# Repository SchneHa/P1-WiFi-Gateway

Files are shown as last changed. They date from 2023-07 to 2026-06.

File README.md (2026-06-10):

### P1-WiFi-Gateway
P1-WiFi-Gateway mit Unterstützung der cFos Power Brain Wallbox

P1 wifi gateway 2022

**(English Version below)**

Basierend auf einem Repo von Ronald Leenes: https://github.com/romix123/P1-wifi-gateway

Diese Software vereint verschiedene Komponenten in einem handlichen Paket.
Die Software läuft auf einem ESP8266 board wie dem Wemos D1 mini oder mini Pro und hat einen bescheidenen Platzbedarf.

Die Datenverarbeitung basiert auf: http://domoticx.com/p1-poort-smart-meter-data-to-domoticz-esp8266 
Das Captive Portal basiert auf einem der ESP8266-Beispiele, die OTA-Einheit ebenfalls.

Das Modul liefert Daten über JSON- oder MQTT-Nachrichten an einen Host, kann aber auch über das Webinterface des Moduls oder per Telnet ausgelesen werden. Die Daten können an einen virtuellen Zähler "HTTP input" in der Power Brain Wallbox von cFos übertragen werden und dort für das Lastmanagement genutzt werden. Damit das funktioniert, muss der Charging Manager der Wallbox mindestens auf die Firmwareversion 1.17.4-beta gebracht werden.

Das Modul lädt beim Start zuerst den Pufferkondensator auf. Es blinkt dann 2x und versucht zunächst, sich mit Ihrem WLAN-Netzwerk zu verbinden. Während dieses Vorgangs blinkt die LED mit einer Periode von 0,5 Hz. Kommt keine Verbindung zustande, startet das Modul einen Access Point mit dem Namen P1_Setup. Verbinden Sie sich mit diesem Netzwerk und surfen Sie zu 192.168.4.1

Daraufhin erscheint der Menübildschirm des Moduls. Geben Sie dort die SSID und das Passwort Ihres WLAN-Netzwerks ein. Darunter tragen Sie die Daten des empfangenden Servers (IP und Portnummer) ein. Dies kann Ihr Domotociz-Server sein, in diesem Fall müssen Sie auch die IDx eingeben, die Domoticz für ein Gas- und ein Energiegerät erstellt. 
Auch die Daten für einen (z. B. auf einem Raspberry Pi selbst gehosteten) MQTT-Broker können jetzt eingegeben werden.

Wenn die Daten für das Lastmanagement einer cFos Power Brain Wallbox genutzt werden sollen, ist dies ebenfalls hier möglich.

In der jetzt veröffentlichten Version 1.2f ist es nun auch möglich, Gas-Verbrauchswerte über MQTT zu empfangen, die von einem Gassensor wie in meinem Repo https://github.com/SchneHa/Gas_Meter beschrieben gesendet werden. Es werden im Webinterface des P1-Gateways der Gas-Gesamtzähler und der aktuelle Tageszähler dargestellt. Dafür kann derselbe Broker wie für die anderen Werte angegeben werden, es kann aber auch ein anderer Broker sein.

Schließlich geben Sie an, wie viele Sekunden Daten an den Server gesendet werden sollen. DSMR4-Messgeräte verwenden ein Messintervall von 10 Sekunden. SMR5-Zähler liefern jede Sekunde Daten. Das erscheint  viel und das Modul benötigt auch viel Strom, daher ist die Frage, ob es parasitär (powered by the meter) arbeiten kann. Empfohlen ist  ein Intervall von 15 Sekunden oder höher. Das hier eingegebene Intervall wird nicht immer synchron zum Datenintervall des Zählers sein, gehen Sie also nicht davon aus, dass Sie in Domoticz, MQTT oder im Charging Manager der cFos Wallbox  genau alle x Sekunden einen Messwert sehen. 

Das Modul „schläft“ zwischen den Messungen (das Modem wird ausgeschaltet, so dass die Stromaufnahme von ca. 70 mA auf 15 mA sinkt). Dies gibt dem Pufferkondensator Zeit, sich für die vom WLAN-Sender des Moduls erzeugten Stromspitzen aufzuladen (und es spart dennoch etwas Strom (der von Ihrem Energieversorger bezahlt wird, aber trotzdem)). Jedes bisschen hilft.

Siehe http://esp8266thingies.nl für weitere Informationen über das Modul und http://www.esp8266thingies.nl/wp/forum-2/ für das Diskussionsforum.

Ergänzung vom 31.07.2023: Seit heute sind die PCB Dateien im KiCAD Format online. Das Board wurde schon produziert und getestet. Ebenso stehen die Gerber Dateien zur Verfügung.

grafik







Ich habe noch einige PCBs aus der ersten Produktion übrig, bei Bedarf bitte melden.
```
PCB unbestückt: 5€
PCB mit Bauteilen: 10€
PCB fertig bestückt: 15€
D1 mini ESP8266 mit Headern: 10€
inklusive Versand innerhalb Deutschlands
hans(dot)schneider(at)gmx(dot)ch
```

```
Version: 1.2f Datum: 29. Mai 2026
         Gasverbrauch (Gesamtzähler und Tageszähler), Import der Werte über MQTT implementiert
         Voraussetzung: Vorhandensein eines Gas-Sensors wie unter meinem Repo
         https://github.com/SchneHa/Gas_Meter beschrieben
Version: 1.2e Datum: 02.11.2025
         Checkt nun in jedem loop, ob eine Verbindung zum WiFi besteht. Wenn nicht, wird die
         Verbindung neu hergestellt.
Version: 1.2d Datum: 15.01.2025
         nach Ändern des voreingestellten Passworts für die cFos Power Brain wird das Passwort
         nun nicht mehr vergessen
Version: 1.2c Datum: 23.05.2024
         die Anzeige der Seite mit den Messwerten wird nun alle 20 Sekunden erneuert
         P1meter sendet nun positive Werte für actualElectricityPowerDelivered und negative Werte
         für actualElectricityPowerReturned zur cFos Power Brain Wallbox (das ist wichtig um
         korrekte Werte für die Einspeisung ins Stomnetz zu erhalten)
Version: 1.2b Datum: 22.05.2023
         Anpassungen für die Firmware 1.19.4 der cFos Power Brain Wallbox
         (power_va ist nun power_w, is_va existiert nicht mehr)
         Korrekturen der niederländischen, französischen und schwedischen Version
Version: 1.2a Datum: 13.03.2023
         Fertigstellung der französischen und schwedischen Version
         diverse Verbesserungen und Fehlerbehebungen
Version: 1.2 Datum: 05.03.2023, Autor: Hans Schneider
         Unterstützung für den HTTP_input Zähler der cFos Power Brain Wallbox hinzugefügt
         diverse Verbesserungen und Fehlerbehebungen
Version: 1.1adc Datum: 12.02.2023 Autor: Ronald Leenes
1.1adc: Umfangreiche Protokollierung implementiert
        Schwedische Version aktualisiert, um sie an die niederländische Version anzugleichen 
        (Deutsche und Französische Version haben keine Sicherheitsfunktionen bei Setup/Update)
1.1aa: Fehlerkorrekturen 1.1: Graphen implementiert BerichtstarifIndicatorElectricity behoben
ud: Kopfzeilen aktualisieren behoben ua: Problem mit Setup-Feldern behoben
u: Passwortschutz für Setup- und Update-Firmware-Menüs hinzugefügt
   Gehen Sie beim ersten Booten von Version 1.0u innerhalb von 60 Sekunden zum Setup-Menü, um den
   Passwortschutz zu umgehen
   Out-of-the-Box-Unterstützung für die Integration von Home Assistant "DSMR Reader" hinzugefügt 
   Verwenden Sie „dsmr“ als MQTT-Präfix und Daten werden automatisch im „DSMR Reader“-Format an den
   MQTT-Broker geliefert
   MQTT-Wiederverbindung behoben, es ist jetzt nicht blockierend
   Zurücksetzen der Hardboot-Tageszähler behoben
   Senden leerer MQTT-Nachrichten behoben
   Insgesamt verbesserte Stabilität
t: Verbesserungen bei der Energieverwaltung
   allgemeine (kleinere) Bereinigung
ta: Korrektur für Telnet-Berichte
    französische Lokalisierung hinzugefügt
s: deutsche Lokalisierung hinzugefügt 
   mqtt-Ausgabe für schwedische spezifische OBIS-Codes hinzugefügt
r: Geschwindigkeitsverbesserungen und Rationalisierung der Parser-Lokalisierungen für: NL, SE
q: Tageswerte hinzugefügt 
p: EquipmentID in mqtt set eingebaut 
o: fixe Gasleistung, fixes mqtt reconnect 
n: leerer Aufruf von SetupSave leitet jetzt zum Hauptmenü weiter statt Einstellungen zurückzusetzen ;-)
   behobene kWh/Wh Invertierung 
m: setupsave fix, relocate to p1wifi.local nach 60 Sek. mqtt 
   kw/W fix 
l: wifireconnect nach WLAN-Verlust 
k: großer BUG behoben, SoftAP würde keinen erreichbaren Webserver erzeugen 
j: Rohdaten auf Port 23
   Hauptcodeumschreibung 
   implementierte Datenberichtsmethoden: geparste Daten: json, mqtt, p1wifi.local/P1 
   Rohdaten: Telnet auf Port 23, p1wifi.local/Data
i: erweiterte maximale Leitungslänge für TD210-D-Zähler, die eine wirklich lange 1-0:99.97.0-Leitung haben 
h: erweitertes mqtt-Set mit sofortigen Leistungen, Spannungen, aktueller Tarifgruppe 
   Stromausfälle, Stromabfälle 
g: feste mqtt
```

Empfohlenes Board:

Wemos D1 mini Pro, Flash Größe: 16 MB, FS: 14 MB, OTA: ~1019 kB

ebenso möglich:

Wemos D1 R2 & mini, Flash Größe: 4 MB, FS: 2 MB, OTA: ~1019 kB oder jedes andere kompatible board

```
Benötigte Dateien:
  P1WG2022current.ino
  CRC16.h 
  JSON.ino 
  MQTT.ino 
  TELNET.ino 
  debug.ino 
  decoder.ino 
  functions.ino 
  graph.ino
  logging.ino
  vars.h
  webserver.ino
  webserverDE.ino
  webserverFR.ino
  webserverNL.ino
  webserverSE.ino
  wifi.ino
```
Anmerkung: <Del>Zurzeit sind nur die deutsche und die niederländische Versionen lauffähig.</Del> Bei der französischen und der schwedischen Version muss ggf. die Übersetzung korrigiert werden.

**English Version:**

P1-WiFi-Gateway with support for cFos Power Brain Wallbox

P1 wifi gateway 2022

Based on a repo of Ronald Leenes: https://github.com/romix123/P1-wifi-gateway

This software combines various components in one handy package.
The software runs on an ESP8266 board like the Wemos D1 mini or mini Pro and has a modest footprint.

The data processing is based on: http://domoticx.com/p1-poort-smart-meter-data-to-domoticz-esp8266
The captive portal is based on one of the ESP8266 samples, as is the OTA unit.

The module delivers data to a host via JSON or MQTT messages, but can also be read out via the module's web interface or via Telnet. It is possible to send data to a virtual meter "HTTP input" of the Power Brain Wallbox of cFos which can be used to implement load management. For that to work Charging Manager of cFos Power Brain Wallbox has to be at least on firmware version 1.17.4-beta.

When starting, the module first charges the buffer capacitor. It will then blink 2x and first try to connect to your WiFi network. During this process, the LED flashes with a period of 0.5 Hz. If no connection is established, the module starts an access point with the name P1_Setup. Connect to this network and surf to 192.168.4.1

The module menu screen appears. Enter the SSID and password of your WiFi network there. Below this, enter the data of the receiving server (IP and port number). This can be your Domotociz server, in this case you also have to enter the IDx that Domoticz creates for a gas and an energy device.
The data for an MQTT broker (e.g. hosted on a Raspberry Pi itself) can now also be entered.

If the data is to be used for load management of a cFos Power Brain Wallbox, this is also possible here.

In the newly released version 1.2f, it is now also possible to receive gas consumption data via MQTT, sent by a gas sensor as described in my repository https://github.com/SchneHa/Gas_Meter. The total gas meter reading and the current daily meter reading are displayed in the P1 gateway's web interface. The same broker used for the other values can be specified for this, or a different broker can be used.

Finally, specify how many seconds of data should be sent to the server. DSMR4 gauges use a measurement interval of 10 seconds. SMR5 counters provide data every second. That seems a lot to me and the module also draws a lot of current, so the question is whether it can operate parasitically (powered by the meter). I recommend an interval of 15 seconds or higher. The interval entered here will not always be in sync with the meter's data interval, so don't assume that you will see a reading in Domoticz, MQTT or in Charging Manager of the cFos Wallbox exactly every x seconds. 

The module "sleeps" between the measurements (the modem is switched off so that the current consumption drops from approx. 70 mA to 15 mA). This gives the buffer capacitor time to charge up for the current spikes generated by the module's WiFi transmitter (and it still saves some electricity (which is paid for by your utility, but still)). Every little helps.

See http://esp8266thingies.nl for more information about the module and http://www.esp8266thingies.nl/wp/forum-2/ for the discussion forum.

Addition from 07/31/2023: Since today the PCB files in KiCAD format are online. The board has already been produced and tested. The Gerber files are also available.

grafik







I still have some PCBs left from the first batch, please let me know if you need one.

```
PCB unassembled: 5€
PCB with parts: 10€
PCB assembled: 15€
D1 mini ESP8266 with headers: 10€
shipping to Germany included
hans(dot)schneider(at)gmx(dot)ch
```

```
Version: 1.2f Date: 29.5.2026
         Gas consumption (Total counter and daily counter), import of the values via MQTT implemented
         Requirement: A Gas sensor as described in my repo https://github.com/SchneHa/Gas_Meter must
         be available
Version: 1.2e Date: 02.11.2025
         now checks connection to wifi in every loop, if not connected it will be reconnected
Version: 1.2d Date: 15.01.2025
         after changing cFos Power Brain password from it's default the new password isn't forgotten anymore now
Version: 1.2c Date: 23.05.2024
         measurement page refreshes every 20 seconds now
         P1meter now sends positive values for actualElectricityPowerDelivered and negative values for
         actualElectricityPowerReturned to cFos Power Brain wallbox (that is important to calculate correct
         values for feeding energy into the power grid)
Version: 1.2b Date: 22.05.2023
         changes for cFos Power Brain Firmware 1.19.4
         (power_va is now power_w, is_va doesn't exist anymore)
         improvements of dutch, french and swedish language
Version: 1.2a Date: 13.03.2023
         Finishing the french and swedish Version
         various Improvements and bug fixes
Version: 1.2 Date: 03/05/2023, Author: Hans Schneider
         added Support for the HTTP_input meter of cFos Power Brain Wallbox
         various improvements and bug fixes
Version: 1.1adc Date: 02/12/2023 Author: Ronald Leenes
1.1adc: Extensive logging implemented
        Swedish version updated to match Dutch version 
        (German and French versions have no security features on setup/update)
1.1aa: Bug fixes 1.1: Graphs implemented
       Reporting TariffIndicatorElectricity fixed
ud: fixed update headers 
ao: fixed problem with setup fields
u: Added password protection for setup and update firmware menus when booting version 
1.0u for the first time, go to setup menu within 60 seconds to bypass password protection
     Added out-of-the-box support for Home Assistant "DSMR Reader" integration 
     Use "dsmr" as MQTT prefix and data is automatically delivered to the MQTT broker in "DSMR Reader" format
     Fixed MQTT reconnection, it's non-blocking now
     Fixed resetting hardboot day counters
     Fixed sending empty MQTT messages
     Improved overall stability
t: Power management improvements
   general (minor) cleanup 
ta: Fix for telnet reports
    added French localization
s: added german localization
   added mqtt output for swedish specific OBIS codes
r: Speed improvements and streamlining of parser 
   localizations for: NL, SE
q: daily values added 
p: EquipmentID built into mqtt set 
o: fixed gas power
   fixed mqtt reconnect 
n: empty call to SetupSave now redirects to main menu instead of resetting settings ;-)
   fixed kWh/Wh inversion 
m: setupsave fix, relocate to p1wifi.local after 60 sec. 
   mqtt - kw/W fix 
l: wifi reconnect after WLAN loss 
k: major BUG fixed
   SoftAP would not create an accessible web server 
j: raw data on port 23 
   main code rewrite
   implemented data reporting methods: parsed data: json, mqtt, p1wifi.local/P1 
   raw data: telnet on port 23, p1wifi.local/Data
i: extended maximum line length for TD210-D meters that have a really long 1-0:99.97.0 line 
h: extended mqtt set with instantaneous powers, voltages, current tariff group
   blackouts, blackouts 
g: fixed mqtt
```

Recommended board:

Wemos D1 mini Pro, Flash Größe: 16 MB, FS: 14 MB, OTA: ~1019 kB

also possible:

Wemos D1 R2 & mini, Flash Größe: 4 MB, FS: 2 MB, OTA: ~1019 kB or any other compatible board

Files needed:
```
  P1WG2022current.ino
  CRC16.h
  JSON.ino
  MQTT.ino
  TELNET.ino
  debug.ino
  decoder.ino
  functions.ino
  graph.ino
  logging.ino
  var.h
  webserver.ino
  webserverDE.ino
  webserverFR.ino
  webserverNL.ino
  webserverSE.ino
  wifi.ino
```

Note: <Del>Only the German and Dutch versions are currently working.</Del> The French and the Swedish version needs improvement of translation.

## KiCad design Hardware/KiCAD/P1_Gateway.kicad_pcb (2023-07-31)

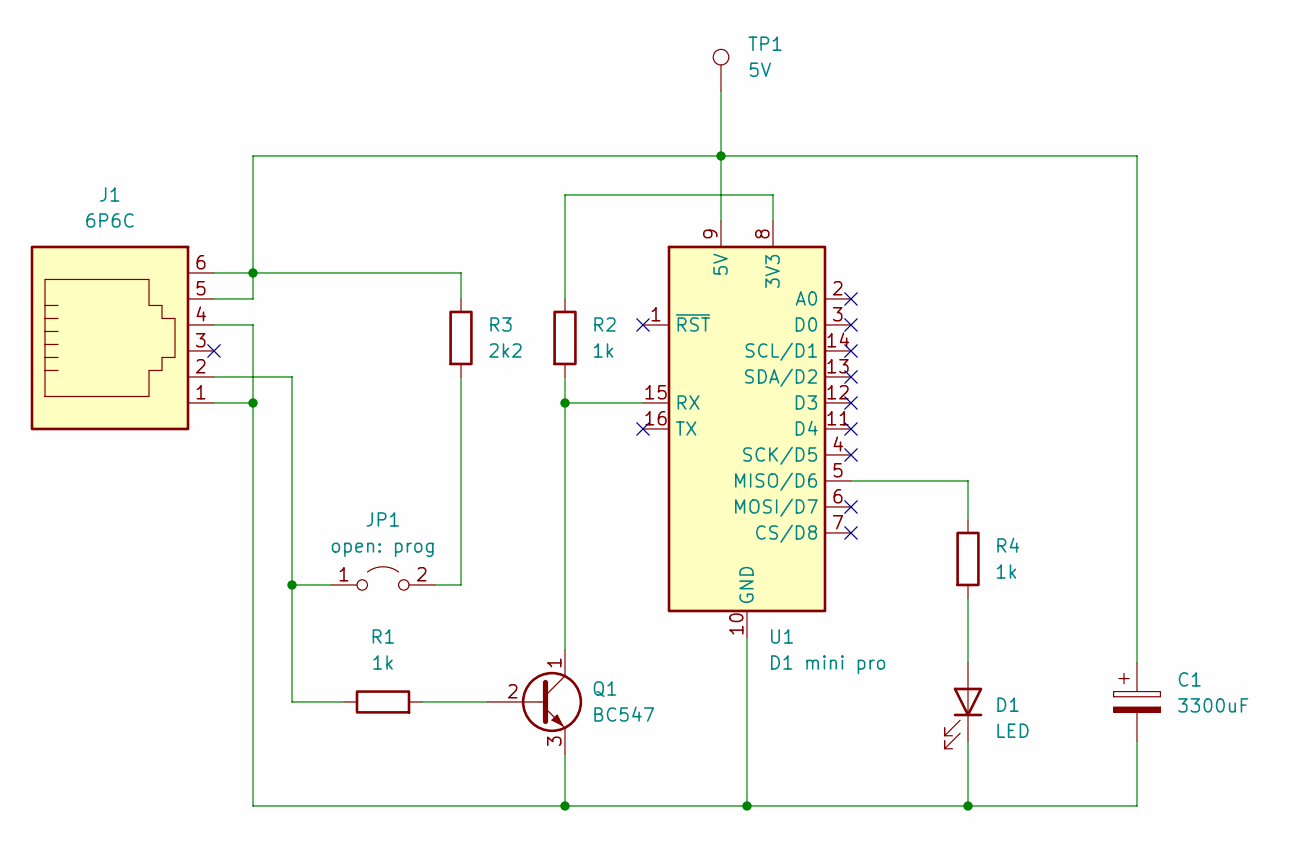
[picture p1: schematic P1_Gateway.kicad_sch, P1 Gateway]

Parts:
C1: 3300uF; CP_Radial_D5.0mm_P2.50mm
D1: LED; LED_D3.0mm
J1: 6P6C; RJ12_Amphenol_54601
JP1: open: prog; TestPoint_2Pads_Pitch2.54mm_Drill0.8mm
Q1: BC547; TO-92L_Inline_Wide
R1, R2, R4: 1k; R_Axial_DIN0204_L3.6mm_D1.6mm_P7.62mm_Horizontal
R3: 2k2; R_Axial_DIN0204_L3.6mm_D1.6mm_P7.62mm_Horizontal
TP1: 5V; TestPoint_Keystone_5000-5004_Miniature
U1: D1 mini pro; WEMOS_D1_mini_light

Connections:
unnamed: C1.1, J1.5, J1.6, R3.1, TP1.1, U1.9 (5V)
unnamed: C1.2, D1.1 (K), J1.1, J1.4, Q1.3 (E), U1.10 (GND)
unnamed: D1.2 (A), R4.2
unnamed: J1.2, JP1.1 (A), R1.1
unnamed: JP1.2 (B), R3.2
unnamed: Q1.1 (C), R2.2, U1.15 (RX)
unnamed: Q1.2 (B), R1.2
unnamed: R2.1, U1.8 (3V3)
unnamed: R4.1, U1.5 (MISO/D6)

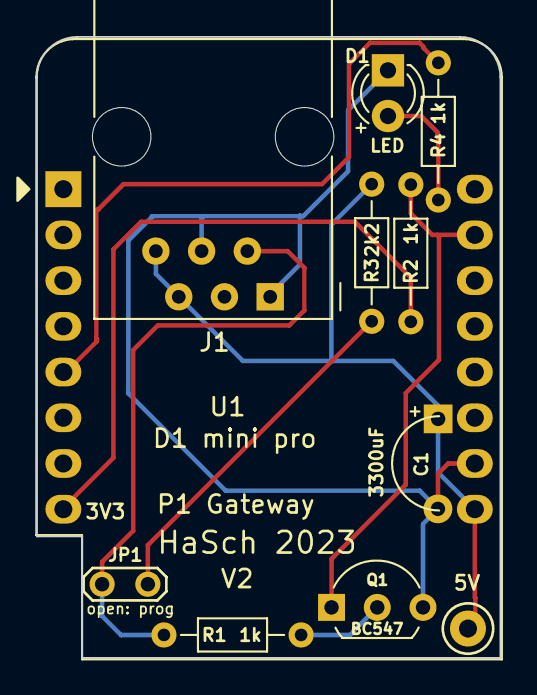
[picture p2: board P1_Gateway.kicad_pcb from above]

Board: 2 copper layers, 25.8 x 34.5 mm, 11 parts (0 on the bottom side), 9 nets.

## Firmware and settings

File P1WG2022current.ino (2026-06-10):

#include <ESP8266LLMNR.h>

 /*
 * Copyright (c) 2022 Ronald Leenes
 *
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
 */
/*
 * @file P1WG2022current.ino
 * @author Ronald Leenes
 *         Hans Schneider
 * @date 02.11.2025
 * @version 1.2f
 *
 * @brief This file contains the main file for the P1 wifi gatewway
 *
 * @see http://esp8266thingies.nl
 */
 
/*
 * P1 wifi gateway 2022
 * 
 * Deze software brengt verschillende componenten bij elkaar in een handzaam pakket.
 * 
 * De software draait op een ESP8285 of ESP8266 en heeft een bescheiden voetafdruk.
 * 
 * De data processing is gebaseerd op: http://domoticx.com/p1-poort-slimme-meter-data-naar-domoticz-esp8266/
 * De captive portal is gebaseerd op een van de ESP8266 voorbeelden, de OTA eenheid eveneens.
 * 
 * De module levert data aan een host via JSON of MQTT messages, maar kan ook via de webinterface van de module of via telnet worden uitgelezen
 * 
 * De module zal bij opstarten eerst de buffercondensator laden. 
 * Vervolgens knippert hij 2x en zal eerst proberen te koppelen aan je wifi netwerk. Gedurende dat proces zal de LED knipperen
 * met een periode van 0.5 Hz.
 * Wanneer geen verbinding kan worden gemaakt start de modiule een Access point onder de naam P1_Setup
 * Verbind met dit netwerk en surf naar 192.168.4.1
 * 
 * Het menuscherm van de module verschijnt dan. Vul daar SSID en wachtwoord van je wifi netwerk in. 
 * Daaronder vul je gegevens van de ontvangede server in (IP en poortnummer). Dit kan je DOmotociz server zijn
 * In dat geval moet je ook het IDx dat Domoticz maakt voor een Gas device en een Energy device invoeren.
 * Tenslotte geef je aan per hoeveel seconde je data naar de server wilt laten sturen.
 * DSMR4 meters hanteren een meetinterval van 10 sec. SMR5 meters leveren iedere seconde data. Dat lijkt me wat veel en 
 * kost de module ook veel stroom waardoor het maar de vraag is of hij parasitair (door de meter gevoed) kan werken.
 * Ik raad een interval van 15 sec of hoger aan. Het interval dat je hier invoert zal niet altijd synchroon lopen met
 * het data interval van de meter, ga er dus niet van uit dat je exact iedere x seconden een meetwaarde ziet in DOmoticz. 
 * Tussen metingen 'slaapt' de module (de modem wordt afgeschakeld waardoor het stroomverbruik van zo'n 70mA terugvalt naar 15 mA). 
 * Dit geeft de bufferelco tijd omm op te laden voor de stroompiekjes die de wifi zender van de module produceert 
 * (en het bespaart hoe dan ook wat stroom (die weliswaar door je energieleverancier wordt betaald, maar toch). Alle kleine 
 * beetjes helpen..
 *
 *  informatie, vragen, suggesties ed richten aan romix@macuser.nl 
 *  
 *  
 *    
 *  versie: 1.2f
 *  datum:  29 Januar 2026
 *  auteur: Ronald Leenes
 *          Hans Schneider
 *
 *  1.2f   implemented reading Gas values provided of an extern smart gas meter via MQTT
 *  1.2e   now checks connection to wifi in every loop, if not connected it will be reconnected
 *  1.2d   after changing cFos Power Brain password from it's default the new password isn't now forgotten anymore
 *  1.2c   measurement page refreshes every 20 seconds now
 *         P1meter now sends positive values for actualElectricityPowerDelivered and negative values for
 *         actualElectricityPowerReturned to cFos Power Brain wallbox. That is important to calculate correct
 *         values for feeding energy into the power grid.         
 *  1.2b   changes for cFos Power Brain FW 1.19.4: power_va is now power_w, is_va doesn't exist anymore
 *         improvements of Netherlands, French and Swedish language 
 *  1.2ab  display of module voltage in footer of webserver pages (re)activated, bug fixes
 *  1.2a:  debugging French and Swedish versions and improvements of translations (needs to be checked)        
 *  1.2:   bug fixes
 *         improvements for T211 SmartMeter in Belgium
 *         implemented support for HTTP input meter in cFos Power Brain wallbox  
 *           note: for this to work your cFos Charging Manager firmware has to be at least 1.17.4-beta
 *         debugging French and Swedish versions and improvemehandlents of translations (needs to be checked)
 *  1.1b   cleaning up, bug fixes, cosmetic changes
 *  1.1adc
 *  1.1ad: bug fixes and graph improvements
 *  1.1aa: bug fixes
 *  1.1: implemented graphs
 *  
 *  
 *  ud: fixed refreshheader
 *  ua: fixed setup field issue
 *  u: 
 *    password on Setup and Firmware Update
 *    made mqtt re-connect non-blocking
 *    incorporated "DSMR Reader" mqtt topics 
 *    fixed hardboot daycounters reset
 *    fixed sending empty MQTT messages
 *  
 *  t: improvements on powermanagement, overall (minor) cleanup
 *  ta: fix for Telnet reporting
 *  
 *  s: added German localisation
 *        Added mqtt output for Swedish specific OBIS codes
 *        
 *  r: speed improvements and streamlining of the parser
 *      localisations for: NL, SE
 *      
 *  q: added daily values
 *  p: incorporated equipmentID in mqtt set
 *  o: fixed gas output, fixed mqtt reconnect
 *  n: empty call to SetupSave now redirects to main menu instead of resetting settings ;-)
 *      fixed kWh/Wh inversion
 *  m: setupsave fix, relocate to p1wifi.local na 60 sec 
 *      mqtt - kw/W fix
 *  l: wifireconnect after wifi loss
 *  k: fixed big BUG, softAP would not produce accessible webserver.
 *  j: raw data on port 23
 *      major code rewrite
 *      implemented data reporting methods: 
 *        parsed data: json, mqtt, p1wifi.local/P1
 *        raw data: telnet on port 23, p1wifi.local/Data
 *        
 *  i:  extended max line length for TD210-D meters, which have a really loong 1-0:99.97.0 line
 *  h:  extended mqtt set with instant powers, voltages, actual tarif group. power outages, power drops
 *  g: fixed mqtt
 *  
 *  Generic ESP8285 module 
 *  Flash Size: 2mb (FS: 128Kb, OTA: –960Kb) 
 *   
 *  needed files: 
 *  this one (obv), 
 *  vars.h            in the process of moving all vars here
 *  lang.h
 *  CRC16.h
 *  JSON.ino
 *  MQTT.ino
 *  TELNET.ino
 *  debug.ino
 *  decoder.ino
 *  functions.ino
 *  graph.ino
 *  webserver.ino
 *  webserverDE.ino 
 *  webserverSE.ino
 *  webserverNL.ino
 *  wifi.ino
 *   
 */

bool zapfiles = false; //false; //true;

#define GERMAN // GERMAN / FRENCH / NEDERLANDS / SWEDISH

#ifdef GERMAN
  String sfx = "DE";
#endif
#ifdef FRENCH
  String sfx = "FR";
#endif
#ifdef NEDERLANDS
  String sfx = "NL";
#endif
#ifdef SWEDISH
  String sfx = "SE";
#endif

String version = "1.2f – " + sfx;

#define HOSTNAME "p1meter"
//#define HOSTNAME_G "Gas"
#define FSystem 1 // 0 = LittleFS 1 = SPIFFS

#define GRAPH 1
#define V3
#define DEBUG 1 //0 //1 //2 //3 // 1 is on serial only, 2 is serial + telnet
#define ESMR5 1
//#define SLEEP_ENABLED

#define LED_BUILTIN 2

const uint32_t  wakeTime = 90000; // stay awake wakeTime millisecs
const uint32_t  sleepTime = 5000; // sleep sleepTime millisecs

#if DEBUG == 1
  const char* host = "P1test";
  #define BLED LED_BUILTIN
  #define debug(x) Serial.print(x)
  #define debugf(x) Serial.printf(x)
  #define debugff(x,y) Serial.printf(x,y)
  #define debugfff(x,y,z) Serial.printf(x,y,z)
  #define debugln(x) Serial.println(x)
#elif DEBUG == 2
  #define BLED LED_BUILTIN
  #define debug(x) Serial.print(x);if(telnetConnected)telnet.print(x)
  #define debugf(x) Serial.printf(x)
  #define debugff(x,y) Serial.printf(x,y)
  #define debugfff(x,y,z) Serial.printf(x,y,z)
  #define debugln(x) Serial.println(x);if(telnetConnected)telnet.println(x)
#elif DEBUG == 3
  const char* host = "P1home";
  #define BLED LED_BUILTIN
  #define debug(x)
  #define debugln(x)
  #define debugf(x)
  #define debugff(x,y)
  #define debugfff(x,y,z)
#else
  const char* host = "P1wifi";
  #define BLED LED_BUILTIN
  #define debug(x)
  #define debugln(x)
  #define debugf(x)
  #define debugff(x,y)
  #define debugfff(x,y,z)
#endif

#define errorHalt(msg) {debugln(F(msg)); return;}

#define NUM(off, mult) ((P1timestamp[(off)] - '0') * (mult))   // macro for getting time out of timestamp, see decoder

#define ToggleLED  digitalWrite(BLED, !digitalRead(BLED));
#define LEDoff  digitalWrite(BLED, HIGH);
#define LEDon   digitalWrite(BLED, LOW);
#define OE  16 //IO16 OE on the 74AHCT1G125 
#define DR  4  //IO4 is Data Request
#define WLED 12  //IO12 (D6) is WiFi-LED, uncomment if it's present

#include <TZ.h>
#define MYTZ TZ_Europe_Amsterdam
#include <TimeLib.h>
#include <coredecls.h> // settimeofday_cb()
#include <MyAlarm.h>

#include <ESP8266WiFi.h>
#include <ESP8266HTTPClient.h>
#include <WiFiUdp.h>
#include "CRC16.h"

#if GRAPH == 1
  #if FSystem == 0
    #include <LittleFS.h>
    #define FST LittleFS
  #elif FSystem == 1
    #include "FS.h" //SPIFFS
    #define FST SPIFFS
  #endif
  File file;
#endif


// van ESP8266WiFi/examples/WiFiShutdown/WiFiShutdown.ino
#ifndef RTC_config_data_SLOT_WIFI_STATE
  #define RTC_config_data_SLOT_WIFI_STATE 33u
#endif
#include <include/WiFiState.h>  // WiFiState structure details
//#include <WiFiState.h>  // WiFiState structure details
WiFiState WiFistate;


//van captive portal
/*  ============================================================================================================

    Captive Portal based on:
    https://gitlab.com/MrDIYca/code-samples/-/raw/master/esp8266_setup_portal.ino

    For more info, please watch my video at https://youtu.be/1VW-z4ibMXI
    MrDIY.ca
  ============================================================================================================== */
#include <EEPROM.h>
#include <ESP8266WebServer.h>
ESP8266WebServer    server(80);

#include <WiFiClient.h>
#include <ESP8266mDNS.h>


// mqtt stuff . https://github.com/ict-one-nl/P1-Meter-ESP8266-MQTT/blob/master/P1Meter/P1Meter.ino
#include <PubSubClient.h>
WiFiClient espClient;                   // * Initiate WIFI client
PubSubClient mqtt_client(espClient);    // * Initiate MQTT client
bool MQTT_Server_Fail = false;
long nextMQTTreconnectAttempt;
// end mqtt stuff

//// Raw data server
#include "ESPTelnet.h"
ESPTelnet telnet;
uint16_t  port = 23;
IPAddress ip;
bool telnetConnected = false;
// end raw data stuff

#include "vars.h"
//#include "lang.h"

struct settings {
  char dataSet[4];
  char ssid[32];
  char password[32];
  char domoticzIP[30] = "IPaddress";
  char domoticzPort[10] = "Port";
  char domoticzEnergyIdx[10] = "EnergyIdx";
  char domoticzGasIdx[10] = "GasIdx";
  char mqttTopic[50] = "sensors/power/p1meter";
  char mqttIP[30] = "";
  char mqttPort[10]  = "";
  char mqttUser[32] = "";
  char mqttPass[32] = "";
  char cfosUsr[32] = "admin";
  char cfosPwd[32] = "1234abcd";
  char cfosIP[30] = "192.168.1.183";
  char cfosPort[10] = "80";
  char cfosID[5] = "M4";
  char cfosModel[30] = "HTTP_Input";
  char interval[3] = "20";
  // char cfosVA[4] = "n";

  // for MQTT Gas
  char mqttGasTopic[20] = "Energy/Gas/Volume";
  char mqttGasTopicT[20] = "Energy/Gas/Daily_m3";
  char mqttGasIP[30] = "";
  char mqttGasPort[10] = "";
  char mqttGasUser[32] = "";
  char mqttGasPass[32] = "";  
  // end MQTT Gas

  char domo[4] = "j";
  char mqtt[4] = "j";
  char cfos[4] = "j";
  
  // for MQTT Gas
  char mgas[4] = "n";
  // end MQTT Gas

  char watt[4] = "n";
  char telnet[4] = "n";
  char debug[4] = "n";
  char adminPassword[32];
} config_data = {};


float RFpower = 0;      //20.5; // (For OdBm of output power, lowest. Supply current~70mA)
                        //20.5dBm (For 20.5dBm of output, highest. Supply current~85mA)

ADC_MODE(ADC_VCC);  // allows you to monitor the internal VCC level;
float volts;


// Vars to store meter readings
// we capture all data in char arrays or Strings for longer hard to delineate data
String P1header;
char P1version[8];
int P1prot;             // 4 or 5 based on P1version 1-3:0.2.8 
char P1timestamp[30]  = "\0";
char equipmentId[100] = "\0";
char electricityUsedTariff1[12];
char electricityUsedTariff2[12];
char electricityReturnedTariff1[12];
char electricityReturnedTariff2[12];
char tariffIndicatorElectricity[8];
char actualElectricityPowerDelivered[8];
char actualElectricityPowerReturned[8];
char numberPowerFailuresAny[6];
char numberLongPowerFailuresAny[6];
String longPowerFailuresLog;
char numberVoltageSagsL1[7];
char numberVoltageSagsL2[7];
char numberVoltageSagsL3[7];
char numberVoltageSwellsL1[7];
char numberVoltageSwellsL2[7];
char numberVoltageSwellsL3[7];
String textMessage;
char instantaneousVoltageL1[7];
char instantaneousVoltageL2[7];
char instantaneousVoltageL3[7];
char instantaneousCurrentL1[9];
char instantaneousCurrentL2[9];
char instantaneousCurrentL3[9];
char activePowerL1P[9];
char activePowerL2P[9];
char activePowerL3P[9];
char activePowerL1NP[9];
char activePowerL2NP[9];
char activePowerL3NP[9];

// Swedish specific
char cumulativeActiveImport[12];    // 1.8.0
char cumulativeActiveExport[12];    // 2.8.0
char cumulativeReactiveImport[12];  // 3.8.0
char cumulativeReactiveExport[12];  // 4.8.0
char momentaryActiveImport[12];     // 1.7.0
char momentaryActiveExport[12];     // 2.7.0
char momentaryReactiveImport[12];   // 3.7.0
char momentaryReactiveExport[12];   // 4.7.0
char momentaryReactiveImportL1[12]; // 23.7.0
char momentaryReactiveImportL2[12]; // 43.7.0
char momentaryReactiveImportL3[12]; // 63.7.0
char momentaryReactiveExportL1[12]; // 24.7.0
char momentaryReactiveExportL2[12]; // 44.7.0
char momentaryReactiveExportL3[12]; // 64.7.0

char reactivePowerL1P[9]; // Sweden uses these 6
char reactivePowerL2P[9];
char reactivePowerL3P[9];
char reactivePowerL1NP[9];
char reactivePowerL2NP[9];
char reactivePowerL3NP[9];
// end Swedish

char deviceType[5];
char gasId[100] = "\0";;
char gasReceived5min[12];
char gasDomoticz[12];       //Domoticz wil gas niet in decimalen?

char prevGAS[12];           // not an P1 protocol var, but holds gas value

// char VolGas[12];
// String Vlm = "";
// String x;

// static char MQTT_EP[64]; // MQTT Empfangspuffer

// char dayStartGaz[12];
// char dayStartUsedT1[12];
// char dayStartUsedT2[12];
// char dayStartReturnedT1[12];
// char dayStartReturnedT2[12];

// char monthStartGaz[12];
// char monthStartUsedT1[12];
// char monthStartUsedT2[12];
// char monthStartReturnedT1[12];
// char monthStartReturnedT2[12];
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
void loop() {
  if (millis() > nextUpdateTime) {//&& monitoring) {
    if (!OEstate) { // OE is disabled  == false
      RTS_on();
      Serial.flush();
    }
  } // update window
  if (OEstate) readTelegram();

  #ifdef SLEEP_ENABLED
    if ((millis() > time_to_sleep) && !atsleep && wifiSta) {  // not currently sleeping and sleeptime
      modemSleep();
    }
    if (wifiSta && (millis() > time_to_wake) && (WiFi.status() != WL_CONNECTED)) { // time to wake, if we're not already awake
      modemWake();
    }
  #endif

  if (datagramValid && (state == DONE) && (WiFi.status() == WL_CONNECTED)) {

    if (Mqtt) {
      doMQTT();
      if (MqttDelivered) {
        datagramValid = false;
        state = WAITING;
        MqttDelivered = false;
      }
    }

    if (Json) {
      doJSON();
      doCFOS();
      datagramValid = false;
      state = WAITING;    
    }

    if (Telnet) {
      TelnetReporter();
      datagramValid = false;
      state = WAITING;
    }

    if (MQTT_debug) MQTT_Debug();
      state = WAITING;
  }  

  if (softAp || (WiFi.status() == WL_CONNECTED)) {
    server.handleClient(); //handle web requests
    MDNS.update();
    if (Telnet) telnet.loop();
  }

  if (millis() > EverSoOften){
    checkCounters();
    resetFlags();
    doWatchDogs();
    EverSoOften = millis() + 22000;
  }
  timerAlarm.update();
  
  if (!softAp)
    if (WiFi.status() != WL_CONNECTED) {
      wifiReconnect();
  }

  mqtt_client.loop();

}

void initTimers(){
  #if DEBUG == 1
    timerAlarm.createHour(59, 0, doHourlyLog);
    timerAlarm.createHour(15, 0, doHourlyLog);
    timerAlarm.createHour(30, 0, doHourlyLog);
    timerAlarm.createHour(45, 0, doHourlyLog);
  #else
    timerAlarm.createHour(59, 0, doHourlyLog);
  #endif
  timerAlarm.createDay(23,58, 0, doDailyLog);
  timerAlarm.createWeek(timerAlarm.dw_Sunday, 23, 59, 0, doWeeklyLog);
  timerAlarm.createMonth(31, 0, 0, 0, doMonthlyLog);
}

void checkCounters() {
  // see logging.ino
//  time_t t = now();
  if (timeIsSet && !TimeTriggersSet) {
    initTimers();
    TimeTriggersSet= true;
  }

  if (coldbootE && gotPowerReading) {
    if (needToInitLogVars) {
      doInitLogVars();
    }
    resetEnergyDaycount();
    resetEnergyMonthcount();
  }
  
  if (coldbootG && gotGasReading) {
    if (needToInitLogVarsGas) {
      doInitLogVarsGas();
    }
    resetGasCount();
  }

//  if (!CHK_FLAG(logFlags, hourFlag) && ( minute() == 10 || minute() == 20 || minute() == 30 || minute() == 40 || minute() == 50) ) doHourlyLog();

// if (!minFlag && second() > 55) doMinutelyLog();

//  if (!CHK_FLAG(logFlags, hourFlag) && minute(t) == 59) doHourlyLog();
//  if (!CHK_FLAG(logFlags, dayFlag) && (hour(t) == 23) && (minute(t) == 59)) doDailyLog();
//  if (!CHK_FLAG(logFlags, weekFlag) && weekday(t) == 1 && hour(t) == 23 && minute(t) == 59) doWeeklyLog(); // day of the week (1-7), Sunday is day 1
//  if (!CHK_FLAG(logFlags, monthFlag) && day(t) == 28 && month(t) == 2 && hour(t) == 23 && minute(t) == 59 && year(t) != 2024 && year(t) != 2028 ) doMonthlyLog();
//  if (!CHK_FLAG(logFlags, monthFlag) && day(t) == 29 && month(t) == 2 && hour(t) == 23 && minute(t) == 59 ) doMonthlyLog(); // schrikkeljaren
//  if (!CHK_FLAG(logFlags, monthFlag) && day(t) == 30 && (month(t) == 4 || month(t) == 6 || month(t) == 9 || month(t) == 11) && hour(t) == 23 && minute(t) == 59 ) doMonthlyLog();
//  if (!CHK_FLAG(logFlags, monthFlag) && day(t) == 31 && (month(t) == 1 || month(t) == 3 || month(t) == 5 || month(t) == 7 || month(t) == 8 || month(t) == 10 || month() == 12) && hour() == 23 && minute() == 59 ) doMonthlyLog();
//  if (!CHK_FLAG(logFlags, monthFlag) && day(t) == 31 && month(t) == 12 && hour(t) == 23 && minute(t) == 59 ) doYearlyLog();
//  doMonthlyLog();
  if (!monthFlag && day() == 31 && (month() == 1 || month() == 3 || month() == 5 || month() == 7 || month() == 8 || month() == 10 || month() == 12) && hour() == 23 && minute() == 59 ) doMonthlyLog();
  if (!monthFlag && day() == 31 && month() == 12 && hour() == 23 && minute() == 59 ) doYearlyLog();
}

void resetFlags() {
//  if (CHK_FLAG(logFlags, hourFlag) &&  (minute() > 0) ) CLR_FLAG(logFlags, hourFlag);// if (hourFlag &&  (minute() > 24)) hourFlag = false; // CLR_FLAG(logFlags, hourFlag);
//  if (CHK_FLAG(logFlags, dayFlag) && (day() > 0)) CLR_FLAG(logFlags, dayFlag);

//  if (CHK_FLAG(logFlags, weekFlag) &&  (weekday() > 1)) CLR_FLAG(logFlags, weekFlag);
//  if (CHK_FLAG(logFlags, monthFlag) &&  (day() > 0)) CLR_FLAG(logFlags, monthFlag);
//  if (CHK_FLAG(logFlags, yearFlag) &&  (day() == 1) && month() == 1) CLR_FLAG(logFlags, yearFlag);
//  debug("logFlags : ");
//  Serial.println(logFlags);
  if (minFlag && (second() > 5) && (second() < 10)) minFlag = false;
  if (checkMinute >= 59) checkMinute = 0; 
  if (hourFlag && ((minute() > (checkMinute + 2)) && (minute() < (checkMinute + 4)))) hourFlag=false;// if (hourFlag &&  (minute() > 24)) hourFlag = false; // CLR_FLAG(logFlags, hourFlag);
  if (dayFlag && (day() > 0)) dayFlag = false;
  if (weekFlag && (weekday() > 1)) weekFlag = false;
  if (monthFlag && (day() > 0)) monthFlag = false;
  if (yearFlag && (day() == 1) && month() == 1) yearFlag = false;
}

void doWatchDogs(){
  char payload[60];
  if (ESP.getFreeHeap() < 2000) ESP.reset(); // watchdog, in case we still have a memery leak
  if (millis() - LastSample > 300000) {
    Serial.flush();
    sprintf(payload, "No data in 300 sec, restarting monitoring: ", timestampkaal());
    if (MQTT_debug) send_mqtt_message("p1wifi/logging", payload);
    hourFlag = false;
    nextUpdateTime = millis() + 10000;
    OEstate = false;
    state = WAITING;
    monitoring=true;
  }
//  if (minute() == 23) hourFlag = false; // clear all flags at a safe timeslot. 
//  if (minute() == 43) hourFlag = false; // clear all flags at a safe timeslot.
//  if (!monitoring && (minute() == 16 || minute() == 31 || minute() == 46)  ) monitoring = true; // kludge to make sure we keep monitoring
}

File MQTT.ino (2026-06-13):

/*
 * Copyright (c) 2022 Ronald Leenes
 *
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
 */

/**
 * @file MQTT.ino
 * @author Ronald Leenes
 * @date 28.12.2022
 *
 * @brief This file contains the MQTT functions 
 *
 * @see http://esp8266thingies.nl
 */

/* MQTT part based on 
 https://github.com/daniel-jong/esp8266_p1meter/blob/master/esp8266_p1meter/esp8266_p1meter.ino

*/

// **********************************
// * MQTT                           *
// **********************************

void doMQTT() {
  mqtt_connect();
  if (MqttConnected) MQTT_reporter();
}

void mqtt_connect() {
  if (!mqtt_client.connected()) {
     MqttConnected = false;
     debugln("Reconnecting to mqtt broker …");
     mqtt_reconnect();
  } else MqttConnected = true;
}

void mqtt_gas_connect() {
  if (!mqtt_client.connected()) {
     MqttGasConnected = false;
     debugln("Reconnecting to mqtt broker …");
     mqtt_reconnect();
  } else MqttGasConnected = true;
}

void mqtt_reconnect() {
  if (millis() > nextMQTTreconnectAttempt) {
    debugln("Attempting MQTT connection...");
    // Create a random client ID
    String clientId = "P1 Smart Meter – ";
    clientId += String(random(0xffff), HEX);
    // Attempt to connect
    if (mqtt_client.connect(HOSTNAME, config_data.mqttUser, config_data.mqttPass)) {
      debugln("   connected to broker");
      // Once connected, publish an announcement...
      mqtt_client.publish("outTopic", "P1 gateway running");
      // ... and resubscribe
      mqtt_client.subscribe("inTopic");

      // for MQTT Gas      
      if (MQTTgas) {
        mqtt_client.subscribe(config_data.mqttGasTopic);
        mqtt_client.subscribe(config_data.mqttGasTopicT);
        }
      // end MQTT Gas    
      MqttConnected = true;
      }
    else {
      debug("failed, rc=");
      debug(mqtt_client.state());
      debugln(" try again later (non blocking)");
      nextMQTTreconnectAttempt = millis() + 2000; // try again in 2 seconds
      MqttConnected = false;
    } 
  }
}

void callback(char* gasTopic, byte* payload, unsigned int length) {
  debug("Message arrived [");
  debug(gasTopic);
  if (String(gasTopic) == String(config_data.mqttGasTopic)) { // Energy/Gas/Volume
    debug("] ");
    r_len=length;
    int i=0;
    for (i; i < length; i++) {
      debug((char)payload[i]);
      buffer[i] = (char)payload[i];
      }
    }
else {
  //if (String(gasTopic) == String(config_data.mqttGasTopicT)); // e.g.: Energy/Gas/Daily_m3
    debug("] ");
    r_lenT=length;
    int j=0;
    for (j; j < length; j++) {
      debug((char)payload[j]);
      bufferT[j] = (char)payload[j];
      }
    }
    debugln();
}

// * Send a message to a broker topic
void send_mqtt_message(const char *topic, char *payload) {
  if (payload[0] == 0) return; //nothing to report
  debug("MQTT Outgoing on > ");
  debug(topic);
  debug(" > ");
  debugln(payload);

  bool result = mqtt_client.publish(topic, payload, false);

  if (!result) {
    debug("MQTT publish to topic: ");
    debug(topic);
    debugln(" failed.");
  }
}

void send_metric(String name, float metric) { // added *long
  char value[20];
  dtostrf(metric, 3, 3, value);
  //  output ftoa(metric, output, 3);
    
  mtopic = String(config_data.mqttTopic) + "/" + name;
  send_mqtt_message(mtopic.c_str(), value); // output
}

void mqtt_send_metric(String name, char *metric) {
  char output[100];
  mtopic = String(config_data.mqttTopic) + "/" + name;
  send_mqtt_message(mtopic.c_str(), metric);
}

void MQTT_reporter() {
  #ifdef NEDERLANDS
    if (mqtt_dsmr){
      mqtt_send_metric("equipmentID", equipmentId);

      mqtt_send_metric("reading/electricity_delivered_1", electricityUsedTariff1);
      mqtt_send_metric("reading/electricity_delivered_2", electricityUsedTariff2);
      mqtt_send_metric("reading/electricity_returned_1", electricityReturnedTariff1);
      mqtt_send_metric("reading/electricity_returned_2", electricityReturnedTariff2);
      mqtt_send_metric("reading/electricity_currently_delivered", actualElectricityPowerDelivered);
      mqtt_send_metric("reading/electricity_currently_returned", actualElectricityPowerReturned);

      mqtt_send_metric("reading/phase_currently_delivered_l1", activePowerL1P);
      mqtt_send_metric("reading/phase_currently_delivered_l2", activePowerL2P);
      mqtt_send_metric("reading/phase_currently_delivered_l3", activePowerL3P);
      mqtt_send_metric("reading/phase_currently_returned_l1", instantaneousCurrentL1);
      mqtt_send_metric("reading/phase_currently_returned_l2", instantaneousCurrentL2);
      mqtt_send_metric("reading/phase_currently_returned_l3", instantaneousCurrentL3);
      mqtt_send_metric("reading/phase_voltage_l1", instantaneousVoltageL1);
      mqtt_send_metric("reading/phase_voltage_l2", instantaneousVoltageL2);
      mqtt_send_metric("reading/phase_voltage_l3", instantaneousVoltageL3);
      mqtt_send_metric("consumption/gas/delivered", gasReceived5min);
      

 //     mqtt_send_metric("meter-stats/actual_tarif_group", tariffIndicatorElectricity[3]);
      send_metric("meter-stats/actual_tarif_group", tariffIndicatorElectricity[3]);
      mqtt_send_metric("meter-stats/power_failure_count", numberPowerFailuresAny);
      mqtt_send_metric("meter-stats/long_power_failure_count", numberLongPowerFailuresAny);
      mqtt_send_metric("meter-stats/short_power_drops", numberVoltageSagsL1);
      mqtt_send_metric("meter-stats/short_power_peaks", numberVoltageSwellsL1);    

      send_metric("day-consumption/electricity1", (atof(electricityUsedTariff1) - atof(log_data.dayE1)));
      send_metric("day-consumption/electricity2", (atof(electricityUsedTariff2) - atof(log_data.dayE2)));
      send_metric("day-consumption/electricity1_returned", (atof(electricityReturnedTariff1) - atof(log_data.dayR1)));
      send_metric("day-consumption/electricity2_returned", (atof(electricityReturnedTariff2) - atof(log_data.dayR2)));

      send_metric("day-consumption/electricity_merged", ((atof(electricityUsedTariff1) - atof(log_data.dayE1)) + (atof(electricityUsedTariff2) - atof(log_data.dayE2))));
      send_metric("day-consumption/electricity_returned_merged", ((atof(electricityReturnedTariff1) - atof(log_data.dayR1)) + (atof(electricityReturnedTariff2) - atof(log_data.dayR2))));
      send_metric("day-consumption/gas", (atof(gasReceived5min) - atof(log_data.dayG)));

      send_metric("current-month/electricity1", (atof(electricityUsedTariff1) - atof(log_data.monthE1)));
      send_metric("current-month/electricity2", (atof(electricityUsedTariff2) - atof(log_data.monthE2)));
      send_metric("current-month/electricity1_returned", (atof(electricityReturnedTariff1) - atof(log_data.monthR1)));
      send_metric("current-month/electricity2_returned", (atof(electricityReturnedTariff2) - atof(log_data.monthR2)));
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

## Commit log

2023-05-18 Update P1WG2022current.ino
    Fixed a bug that prevents starting webservices
    [P1WG2022current.ino]
2023-05-19 Update P1WG2022current.ino
    bug fixes
    [P1WG2022current.ino]
2023-05-20 version 1.2ab
    (re)activated display of module voltage in footer of webserver pages, bug fixes
    [P1WG2022current.ino]
2023-05-21 display of module voltage (re)activated
2023-05-22 Changes for cFos Power Brain FW 1.19.4
    power_va is now power_w, is_va doesn't exist anymore in FW 1.19.4
    improvements of Netherlands, French and Swedish language
    [JSON.ino, P1WG2022current.ino, debug.ino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]
2023-07-31 Update README.md
    Addition: PCB files ready!
2024-05-14 10
    P1meter now sends positive values for actualElectricityPowerDelivered and negative values for actualElectricityPowerReturned to cFos Power Brain wallbox
2024-05-17 2
    now, power_w in cFos Power Brain is displayed correctly
    [JSON.ino, MQTT.ino]
2024-05-19 2
    fixing an annoying bug: now, actualElectricityPowerReturned is handled correctly using cFos wallbox
    [JSON.ino, MQTT.ino]
2024-05-19 Update JSON.ino
    deleting lines inserted for debugging purposes
2024-05-21 Update JSON.ino
    bug fixing
    [JSON.ino]
2025-01-15 cFos user password issue
    after changing cFos Power Brain password from it's default the new password isn't now forgotten anymore
    [JSON.ino, MQTT.ino, P1WG2022current.ino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]
2026-01-28 Fix variable name case for softAP in condition
    [P1WG2022current.ino]

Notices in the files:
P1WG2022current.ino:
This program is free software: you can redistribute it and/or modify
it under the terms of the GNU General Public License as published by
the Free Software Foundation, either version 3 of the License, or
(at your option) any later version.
